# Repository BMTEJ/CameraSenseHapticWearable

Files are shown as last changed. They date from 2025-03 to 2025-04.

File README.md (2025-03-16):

# CameraSenseHapticWearable

A wearable custom PCB with mounted camera, ESP32 Wroom2, haptic feedback, and 3v8 rechargeable battery to sense when wearer is leaving bounds of crosswalk.
If they exiting left, two vibrations, if right, one vibration.

Components:
ESP32-S3-Wroom2
LRA
LRA driver
ArduCam
3V8 LiPo

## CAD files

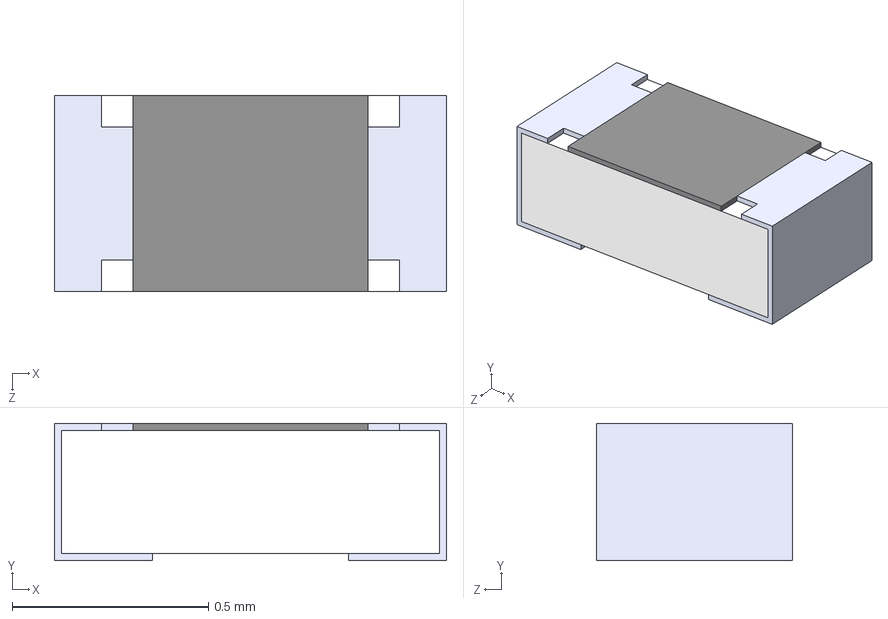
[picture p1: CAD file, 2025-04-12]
PCB/ESP32/ESP32_sym_footprint/ERJ2RKF1600X.step
1 x 0.35 x 0.5 mm

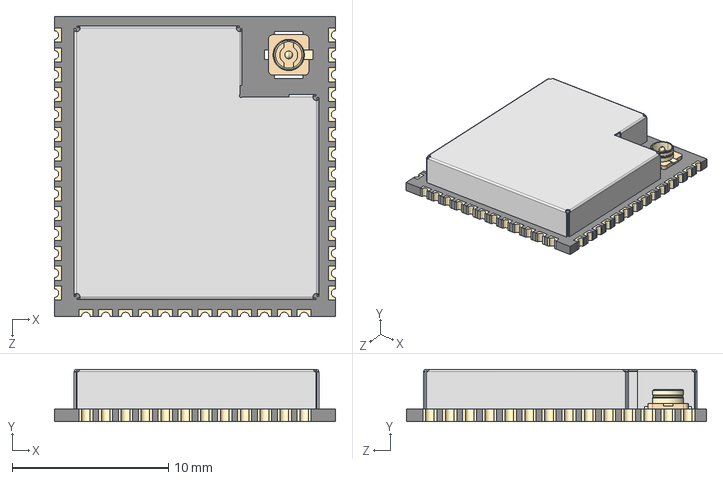
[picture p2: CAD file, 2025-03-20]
PCB/ESP32/ESP32_sym_footprint/ESP32-S2-SOLO-U-N4.step
18.0 x 3.35 x 19.2 mm

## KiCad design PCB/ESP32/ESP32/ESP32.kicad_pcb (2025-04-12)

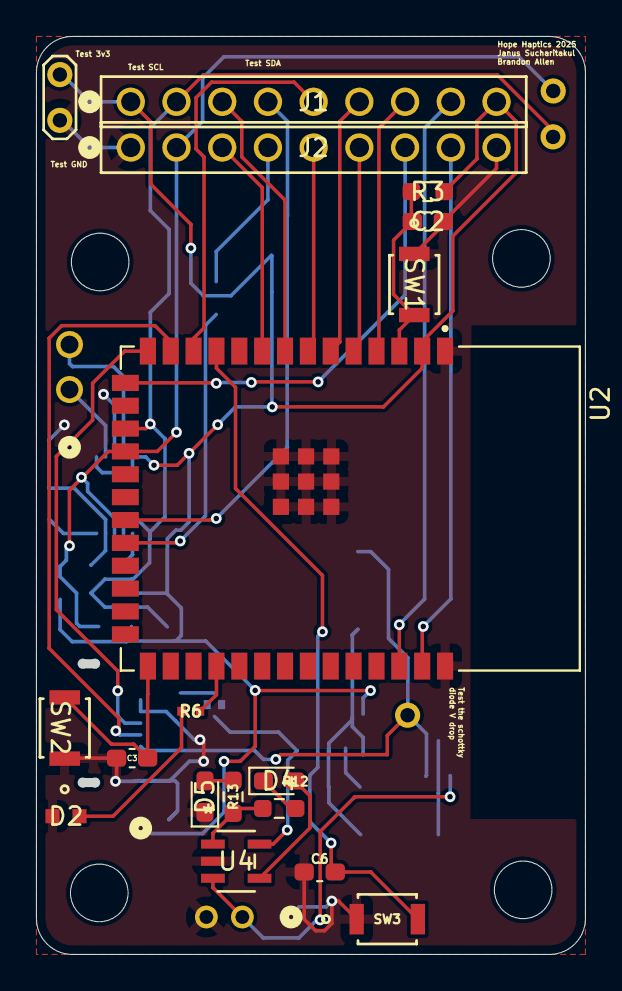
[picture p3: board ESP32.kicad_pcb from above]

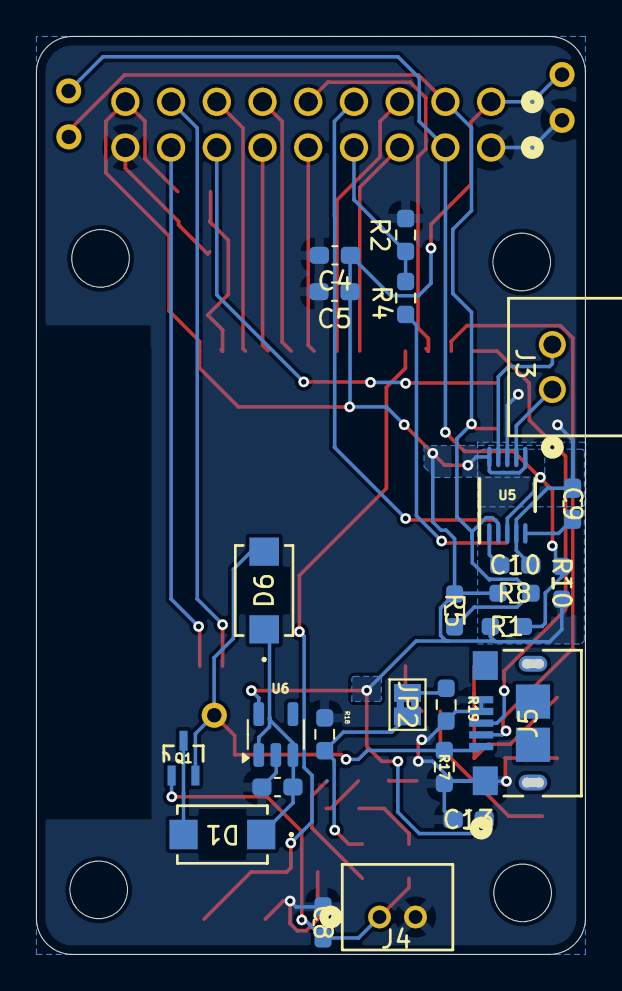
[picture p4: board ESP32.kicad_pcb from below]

Board: 2 copper layers, 30.5 x 51.0 mm, 42 parts (25 on the bottom side), 37 nets.

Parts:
C2, C3, C4, C6, C10: .1uF; C_0603_1608Metric_Pad1.08x0.95mm_HandSolder
C5, C9, C12, C13: 1uF; C_0603_1608Metric_Pad1.08x0.95mm_HandSolder
C8: 10μF; C_0603_1608Metric_Pad1.08x0.95mm_HandSolder
D1, D6: D_Schottky; CR_SMA_403AE_OSI-L
D2: LED; LEDIndicator
D4, D5: LED; D_0603_1608Metric_Pad1.05x0.95mm_HandSolder
J1, J2: PPTC091LFBN-RC; CONN9_PPTC091LFBN-RC_SUL
J3: Conn_01x02_Pin; CONN_S2B-XH-A_JST
J4: Conn_01x02_Socket; CONN2_B2B-PH-K-S_JST
J5: USB_B_Micro; CONN_10118193-0001LF_AMP
JP2: SolderJumper_2_Open; SolderJumper-2_P1.3mm_Bridged2Bar_Pad1.0x1.5mm
Q1: PMOS; SOT65P210X110-3N
R1, R3, R5, R17: 10k; R_0603_1608Metric_Pad0.98x0.95mm_HandSolder
R2, R4: 4.7k; R_0603_1608Metric_Pad0.98x0.95mm_HandSolder
R6: 160hm; RESIndicatpr
R8, R10: 2.2k; R_0603_1608Metric_Pad0.98x0.95mm_HandSolder
R12, R13: 330 ohm; R_0603_1608Metric_Pad0.98x0.95mm_HandSolder
R18: 10K; R_0603_1608Metric_Pad0.98x0.95mm_HandSolder
R19: 2.5K; R_0603_1608Metric_Pad0.98x0.95mm_HandSolder
SW1: RESET; B3U-1000P
SW2: BOOT; B3U-1000P
SW3: LRA Switch; B3U-1000P
U2: ESP32-S2-SOLO-U-N4; XCVR_ESP32-S2-SOLO-N4
U4: MCP73832T-2ACI/OT; SOT-23-5_MC_MCH
U5: DRV2605LTDGSRQ1; DGS0010A_L
U6: AP2112K-3.3; SOT-23-5

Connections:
+3V3: C4.1, C5.1, C13.1, J1.1, J1.9, R1.1, R3.1, R5.1, R8.1, R10.1, U2.2 (3V3), U5.6 (VDD_NC), U5.10 (VDD), U6.5 (VOUT)
/D0: J2.8, U2.39 (IO1)
/D1: J1.8, U2.38 (IO2)
/D2: J2.7, U2.15 (IO3)
/D3: J1.7, U2.4 (IO4)
/D4: J2.6, U2.5 (IO5)
/D5: J1.6, U2.6 (IO6)
/D6: J2.5, U2.7 (IO7)
/D7: J1.5, U2.12 (IO8)
/HS: J2.3, U2.9 (IO16)
/MCLK: R4.1, U2.22 (IO14)
/PCLK: J1.4, U2.21 (IO13)
/SCL: J1.2, R5.2, R8.2, U2.17 (IO9), U5.2 (SCL)
/SDA: J2.2, R1.2, R10.2, U2.18 (IO10), U5.3 (SDA)
/USB_D+: J5.3 (D+), U2.14 (IO20)
/USB_D-: J5.2 (D-), U2.13 (IO19)
/VS: J1.3, U2.8 (IO15)
GND: C2.1, C3.1, C4.2, C5.2, C6.1, C8.2, C9.1, C10.2, C12.1, C13.2, D2.1 (K), D5.1 (K), J2.1, J2.9, J4.2, J5.4 (ID), J5.5 (GND), J5.6 (Shield), R2.2, R17.2, R18.2, R19.1, SW1.1 (A), SW2.1 (A), SW3.1 (A), U2.1 (GND), U2.40 (GND__1), U2.41_1 (EPAD), U2.41_2 (EPAD__1), U2.41_3 (EPAD__2), U2.41_4 (EPAD__3), U2.41_5 (EPAD__4), U2.41_6 (EPAD__5), U2.41_7 (EPAD__6), U2.41_8 (EPAD__7), U2.41_9 (EPAD__8), U4.2, U5.4 (IN_TRIG), U5.8 (GND), U6.2 (GND)
unnamed: D1.2 (A), Q1.3 (S)
unnamed: C12.2, D1.1 (K), D6.1 (K), U6.1 (VIN), U6.3 (EN)
unnamed: D2.2 (A), R6.2
unnamed: D4.2 (A), D6.2 (A), J5.1 (VBUS), Q1.2 (G), R17.1, U4.4
unnamed: D4.1 (K), R12.1
unnamed: D5.2 (A), R13.1
unnamed: J2.4, R2.1, R4.2
unnamed: J3.1, U5.7 (OUT+)
unnamed: J3.2, U5.9 (OUT-)
unnamed: C8.1, J4.1, Q1.1 (D), U4.3
unnamed: JP2.1 (A), R19.2
unnamed: JP2.2 (B), R18.1, U4.5
unnamed: R12.2, R13.2, U4.1
unnamed: C2.2, R3.2, SW1.2 (B), U2.3 (EN)
unnamed: C3.2, SW2.2 (B), U2.27 (IO0)
unnamed: C6.2, SW3.2 (B), U2.11 (IO18)
unnamed: R6.1, U2.30 (IO37)
unnamed: C9.2, U5.5 (EN)
unnamed: C10.1, U5.1 (REG)

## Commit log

2025-03-16 LRA schematic done for now. Will add button to activate LRA to demonstrate use later.
    [LRAdriver.kicad_pcb, LRAdriver.kicad_sch]
2025-03-16 Finalized recharge circuit
    [JanusSchematic.kicad_sch]
2025-03-20 ESP32 S2 schematic done.
    [ESP32-S2-SOLO-U-N4.step, ESP32.kicad_pcb, ESP32.kicad_sch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]
2025-04-03 Create Final Schematic
2025-04-03 Coworking test
    [ESP32.kicad_sch]
2025-04-03 Prelim footprints
    [ESP32.kicad_sch]
2025-04-03 Footprints for battery
    [ESP32.kicad_sch]
2025-04-03 Schottky Diode footprint
    [ESP32.kicad_sch]
2025-04-03 Footprint ad
    Switches footprints and JST footprints
2025-04-03 Footprints finished
    Finished JST, LRA footprint assignment
    [ESP32.kicad_sch]
2025-04-03 Updated footprints for imported circuits
    done
    [ESP32.kicad_sch]
2025-04-03 Updated resistor values
    [ESP32.kicad_sch]
2025-04-03 Updated camera
    [ESP32.kicad_sch]
2025-04-04 Charging schematic done
    [ESP32.kicad_sch]
2025-04-04 ddasd
    as
    [ESP32.kicad_sch]
2025-04-04 das
    dasdas
    [ESP32.kicad_sch]
2025-04-04 New and improved footprint. Started layout
    [ESP32.kicad_pcb, ESP32.kicad_sch]
2025-04-04 dsa
    dsda
    [ESP32.kicad_sch]
2025-04-04 ERC Checkoff
    [ESP32.kicad_sch]
2025-04-06 Entire layout done. DRC can go-. May need to ask about edge cut errors
    [ESP32.kicad_pcb]
2025-04-07 Fixes
    Fixed 3v3 net, added labels for different bus voltages, cleaned up silkscreen.
    [ESP32.kicad_pcb]
2025-04-10 WIP of the new layout.
    [ESP32.kicad_pcb, ESP32.kicad_sch]
2025-04-12 Full final layout. A little over 2sq Inches
    [ERJ2RKF1600X.step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]
